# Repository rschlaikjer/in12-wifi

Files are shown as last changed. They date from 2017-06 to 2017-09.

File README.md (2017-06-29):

# Wifi-enabled clock with IN-12 nixies

### Nixie clock that synchronizes over Network Time Protocol

Relatively simple Nixie clock, but with an automatic time detection twist.
On boot, and then every hour after, the clock will synchronize with a network
time server to ensure that it is still correct. No need to manually set the
time, no need to worry about RE-setting the time for daylight savings.
The core components are the MCU (ATMEGA328P), WiFi chipset (ATWINC1500)
and boost converter for the nixie tubes (MAX1771).

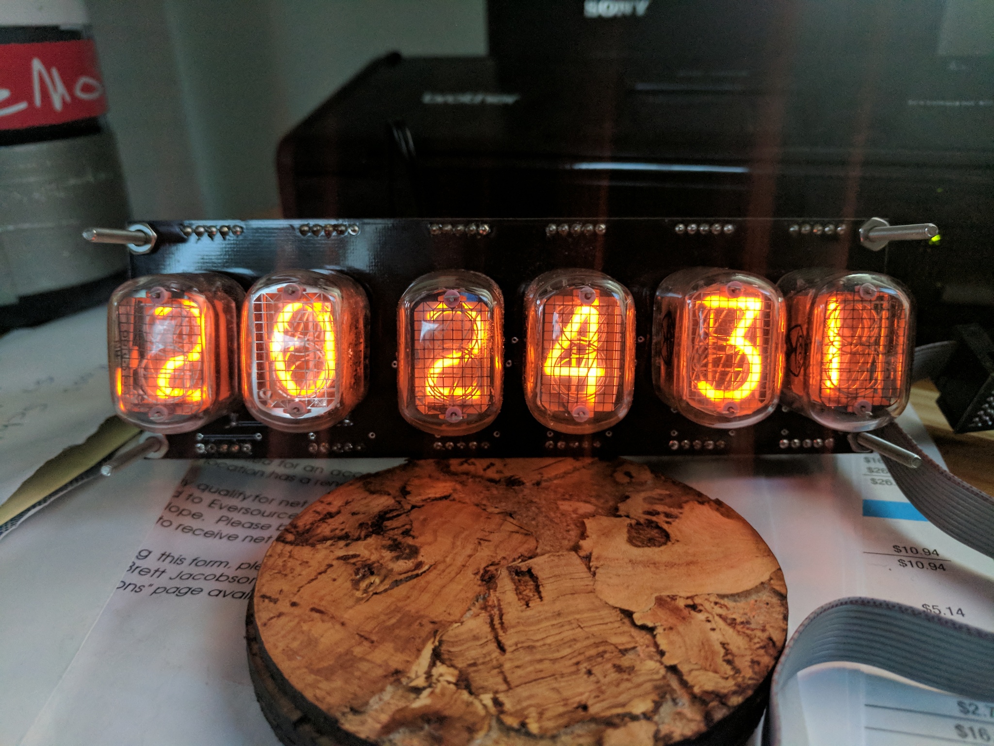
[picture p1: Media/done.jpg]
All set


This project builds on a
[previous clock](https://github.com/rschlaikjer/ntp-nixie)
, which was also NTP-powered but
required a wired internet connection. After the ethernet chipset on that clock
died after a few years continuous service, I resolved to build a second
generation design with two improvements - a seconds place, and wifi enabled to
avoid yet another cable snaking across the desk.

<p align="center">
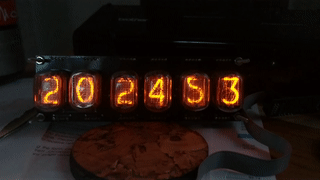
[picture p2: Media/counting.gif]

</p>

The design is split into three PCBs:
- The control board has three sections - one for the boost logic (12V -> 170V),
  one for the wifi logic (at 3.3V), and one for the MCU itsef at 5V.
- The shift register board, middle, simply converts the serial output from the
  MCU on the control board into a parallel output enabling various sinks on the
  nixie pins through MPSA42 transistors.
- The front PCB simply breaks the nixie pins out into even rows at the edges,
  so that it meshes well with the shift register board. Dealing with routing
  the shift registers, current limiting resistors and transistors all on the
  same board as the nixies was too troublesome compared with simply adding
  another layer.

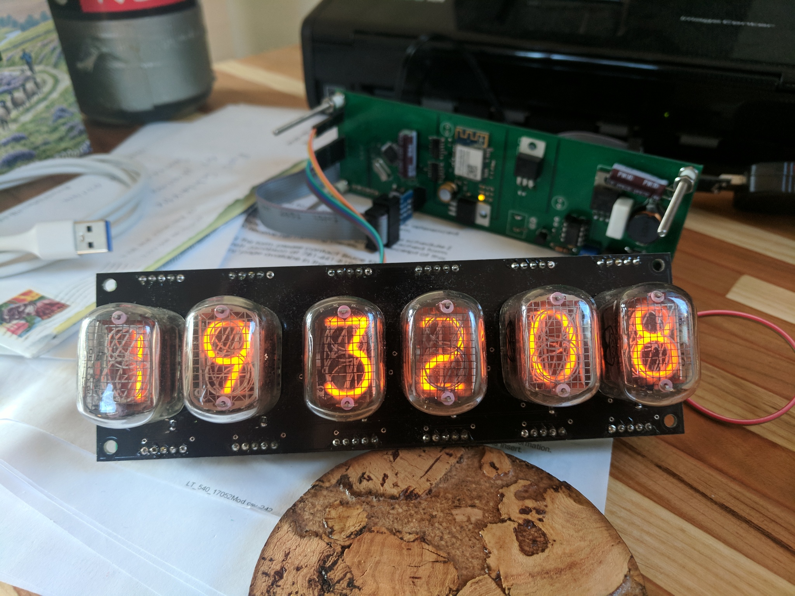
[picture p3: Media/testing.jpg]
Verifying shift register outputs


## BOMs

### Control board

| Part | Value | Device | Package | Description | PROD_ID | VALUE |
| -- | -- | -- | -- | -- | -- | -- |
| C1 | 10uF | CAP0805 | 0805 | Capacitor |  |  |
| C2 | 10uF,25V | CAP_POLPTH2 | CPOL-RADIAL-10UF-25V | Capacitor Polarized |  |  |
| C3 | 10uF/250V | CAP_POLPTH2 | CPOL-RADIAL-10UF-25V | Capacitor Polarized |  |  |
| C4 | 100n | CAPPTH | CAP-PTH-SMALL | Capacitor |  |  |
| C5 | 100n | CAPPTH | CAP-PTH-SMALL | Capacitor |  |  |
| C6 | 100nF | CAP0805 | 0805 | Capacitor |  |  |
| C7 | 10nF | CAP0805 | 0805 | Capacitor |  |  |
| C8 |  | CPOL-USE2,5-6E | E2,5-6E | POLARIZED CAPACITOR, American symbol |  |  |
| C9 |  | CPOL-USE2,5-6E | E2,5-6E | POLARIZED CAPACITOR, American symbol |  |  |
| C10 | 100uF,35V | CAP_POLPTH2 | CPOL-RADIAL-10UF-25V | Capacitor Polarized |  |  |
| C11 | 100nF | CAP0805 | 0805 | Capacitor |  |  |
| C12 | 22pF | CAP0805 | 0805 | Capacitor |  |  |
| C13 | 22pF | CAP0805 | 0805 | Capacitor |  |  |
| C14 | 10uF | CAP0805 | 0805 | Capacitor |  |  |
| C15 |  | CPOL-USE2,5-6E | E2,5-6E | POLARIZED CAPACITOR, American symbol |  |  |
| C16 | 10uF | CAP0805 | 0805 | Capacitor |  |  |
| C17 |  | CPOL-USE2,5-6E | E2,5-6E | POLARIZED CAPACITOR, American symbol |  |  |
| D1 | 1N4007 | 1N4004 | DO41-10 | DIODE |  |  |
| FTDI |  | ARDUINO_SERIAL_PROGRAMPTH | 1X06 | FTDI connector footprints |  |  |
| H1 | STAND-OFF | STAND-OFF | STAND-OFF | #4 Stand Off |  |  |
| H2 | STAND-OFF | STAND-OFF | STAND-OFF | #4 Stand Off |  |  |
| H3 | STAND-OFF | STAND-OFF | STAND-OFF | #4 Stand Off |  |  |
| H4 | STAND-OFF | STAND-OFF | STAND-OFF | #4 Stand Off |  |  |
| IC1 | 7805T | 7805T | TO220H | Positive VOLTAGE REGULATOR |  |  |
| IC3 | ATWINC1500 | ATWINC1500 | ATWINC1500-MR210 | Atmel ATWINC1500-MR210 WiFi/WLAN 802.11 b/g/n |  |  |
| IC4 | LD117AV33 | LD117AV33 | TO220L1 | Low drop fixed and adjustable positive voltage regulators 1 A |  |  |
| ISP1 | AVRISP-6 | AVRISP-6 | AVRISP | AVR ISP HEADER |  |  |
| J1 |  | M04PTH | 1X04 | Header 4 | CONN-09696 |  |
| J2 |  | M02PTH | 1X02 | Standard 2-pin 0.1" header. Use with |  |  |
| J7 |  | M02PTH | 1X02 | Standard 2-pin 0.1" header. Use with |  |  |
| J9 |  | M02PTH | 1X02 | Standard 2-pin 0.1" header. Use with |  |  |
| L1 | 100uH | L-SMT-POWER-B82479 | L-B82479 | SMT power inductors |  |  |
| LED_ACT |  | LED0603 | LED-0603 | LEDs |  |  |
| LED_ERR |  | LED0603 | LED-0603 | LEDs |  |  |
| LED_WIFI |  | LED0603 | LED-0603 | LEDs |  |  |
| Q1 | IRF840 | IRF840 | TO220 | N-Channel Enhancement MOSFET (HEXFET); 500V; 8A; 0,85Ohm |  |  |
| Q2 | MOSFET-NCHANNEL2N7000 | MOSFET-NCHANNEL2N7000 | TO-92 | Common NMOSFET Parts |  |  |
| R1 | 1k | RESISTOR0805-RES | 0805 | Resistor |  |  |
| R2 | 100k | RESISTOR0805-RES | 0805 | Resistor |  |  |
| R3 | 1.5M | RESISTORPTH-1/4W | AXIAL-0.4 | Resistor |  |  |
| R4 | 10k | RESISTORPTH-1/4W | AXIAL-0.4 | Resistor |  |  |
| R5 | 0R050 | RESISTORPTH-1/4W | AXIAL-0.4 | Resistor |  |  |
| R6 | 1lk | RESISTOR0805-RES | 0805 | Resistor |  |  |
| R7 | 1k | RESISTOR0805-RES | 0805 | Resistor |  |  |
| R11 | 100k | RESISTOR0805-RES | 0805 | Resistor |  |  |
| R12 | 100k | RESISTOR0805-RES | 0805 | Resistor |  |  |
| R13 | 100k | RESISTOR0805-RES | 0805 | Resistor |  |  |
| RESET_SW1 | SPST | TACTILE-SWITCH-PTH | TAC-SWITCH-PTH | Tactile Switch 4 Pins, SPST NO |  |  |
| U$3 | MAX1771 | MAX1771 | 8-DIP |  |  |  |
| U$4 | 5k | RTRIM-3362P | RTRIM3362P | BOURNS 3362 - 1/4" Square Trimpot® Trimming Potentiometer |  |  |
| U$19 | PJ-044A | PJ-044A | PJ-044A |  |  |  |
| U1 |  | TXB0104PWRSOIC14 | SO14 | 4-Bit Bi-Directional Level Shifter | IC-11329 |  |
| U2 |  | TXB0104PWRSOIC14 | SO14 | 4-Bit Bi-Directional Level Shifter | IC-11329 |  |
| U3 | ATMEGA328P_TQFP | ATMEGA328P_TQFP | TQFP32-08 |  | IC-09069 | ATMEGA328P_TQFP |
| Y3 | 16MHz | CRYSTALHC49US | HC49US | Various standard crystals. Proven footprints. |  |  |

### Shift register board

| Part | Value | Device | Package | Description | PROD_ID | VALUE |
| -- | -- | -- | -- | -- | -- | -- |
| C1 |  | CAP0805 | 0805 | Capacitor |  |  |
| C2 |  | CAP0805 | 0805 | Capacitor |  |  |
| C3 |  | CAP0805 | 0805 | Capacitor |  |  |
| C4 |  | CAP0805 | 0805 | Capacitor |  |  |
| C5 |  | CAP0805 | 0805 | Capacitor |  |  |
| C6 |  | CAP0805 | 0805 | Capacitor |  |  |
| H1 | STAND-OFF | STAND-OFF | STAND-OFF | #4 Stand Off |  |  |
| H2 | STAND-OFF | STAND-OFF | STAND-OFF | #4 Stand Off |  |  |
| H3 | STAND-OFF | STAND-OFF | STAND-OFF | #4 Stand Off |  |  |
| H4 | STAND-OFF | STAND-OFF | STAND-OFF | #4 Stand Off |  |  |
| IC1 | 74LS595D | 74LS595D | SO16 | 8-bit SHIFT REGISTER, output latch |  |  |
| IC2 | 74LS595D | 74LS595D | SO16 | 8-bit SHIFT REGISTER, output latch |  |  |
| IC3 | 74LS595D | 74LS595D | SO16 | 8-bit SHIFT REGISTER, output latch |  |  |
| IC4 | 74LS595D | 74LS595D | SO16 | 8-bit SHIFT REGISTER, output latch |  |  |
| IC5 | 74LS595D | 74LS595D | SO16 | 8-bit SHIFT REGISTER, output latch |  |  |
| IC9 | 74LS595D | 74LS595D | SO16 | 8-bit SHIFT REGISTER, output latch |  |  |
| J1 |  | M04PTH | 1X04 | Header 4 | CONN-09696 |  |
| J2 |  | M05PTH | 1X05 | Header 5 |  |  |
| J3 |  | M05PTH | 1X05 | Header 5 |  |  |
| J4 |  | M05PTH | 1X05 | Header 5 |  |  |
| J5 |  | M05PTH | 1X05 | Header 5 |  |  |
| J6 |  | M05PTH | 1X05 | Header 5 |  |  |
| J7 |  | M02PTH | 1X02 | Standard 2-pin 0.1" header. Use with |  |  |
| J8 |  | M05PTH | 1X05 | Header 5 |  |  |
| J9 |  | M02PTH | 1X02 | Standard 2-pin 0.1" header. Use with |  |  |
| J10 |  | M05PTH | 1X05 | Header 5 |  |  |
| J11 |  | M05PTH | 1X05 | Header 5 |  |  |
| J12 |  | M05PTH | 1X05 | Header 5 |  |  |
| J13 |  | M05PTH | 1X05 | Header 5 |  |  |
| J14 |  | M05PTH | 1X05 | Header 5 |  |  |
| J15 |  | M05PTH | 1X05 | Header 5 |  |  |
| Q8 | MPSA42 | TRANSISTOR_NPNMPSA42 | SOT23-3 | Generic NPN BJT | TRANS-09116 | MPSA42 |
| Q9 | MPSA42 | TRANSISTOR_NPNMPSA42 | SOT23-3 | Generic NPN BJT | TRANS-09116 | MPSA42 |
| Q10 | MPSA42 | TRANSISTOR_NPNMPSA42 | SOT23-3 | Generic NPN BJT | TRANS-09116 | MPSA42 |
| Q11 | MPSA42 | TRANSISTOR_NPNMPSA42 | SOT23-3 | Generic NPN BJT | TRANS-09116 | MPSA42 |
| Q12 | MPSA42 | TRANSISTOR_NPNMPSA42 | SOT23-3 | Generic NPN BJT | TRANS-09116 | MPSA42 |
| Q13 | MPSA42 | TRANSISTOR_NPNMPSA42 | SOT23-3 | Generic NPN BJT | TRANS-09116 | MPSA42 |
| Q14 | MPSA42 | TRANSISTOR_NPNMPSA42 | SOT23-3 | Generic NPN BJT | TRANS-09116 | MPSA42 |
| Q15 | MPSA42 | TRANSISTOR_NPNMPSA42 | SOT23-3 | Generic NPN BJT | TRANS-09116 | MPSA42 |
| Q16 | MPSA42 | TRANSISTOR_NPNMPSA42 | SOT23-3 | Generic NPN BJT | TRANS-09116 | MPSA42 |
| Q17 | MPSA42 | TRANSISTOR_NPNMPSA42 | SOT23-3 | Generic NPN BJT | TRANS-09116 | MPSA42 |
| Q18 | MPSA42 | TRANSISTOR_NPNMPSA42 | SOT23-3 | Generic NPN BJT | TRANS-09116 | MPSA42 |
| Q19 | MPSA42 | TRANSISTOR_NPNMPSA42 | SOT23-3 | Generic NPN BJT | TRANS-09116 | MPSA42 |
| Q20 | MPSA42 | TRANSISTOR_NPNMPSA42 | SOT23-3 | Generic NPN BJT | TRANS-09116 | MPSA42 |
| Q25 | MPSA42 | TRANSISTOR_NPNMPSA42 | SOT23-3 | Generic NPN BJT | TRANS-09116 | MPSA42 |
| Q26 | MPSA42 | TRANSISTOR_NPNMPSA42 | SOT23-3 | Generic NPN BJT | TRANS-09116 | MPSA42 |
| Q27 | MPSA42 | TRANSISTOR_NPNMPSA42 | SOT23-3 | Generic NPN BJT | TRANS-09116 | MPSA42 |
| Q28 | MPSA42 | TRANSISTOR_NPNMPSA42 | SOT23-3 | Generic NPN BJT | TRANS-09116 | MPSA42 |
| Q29 | MPSA42 | TRANSISTOR_NPNMPSA42 | SOT23-3 | Generic NPN BJT | TRANS-09116 | MPSA42 |
| Q30 | MPSA42 | TRANSISTOR_NPNMPSA42 | SOT23-3 | Generic NPN BJT | TRANS-09116 | MPSA42 |
| Q31 | MPSA42 | TRANSISTOR_NPNMPSA42 | SOT23-3 | Generic NPN BJT | TRANS-09116 | MPSA42 |
| Q32 | MPSA42 | TRANSISTOR_NPNMPSA42 | SOT23-3 | Generic NPN BJT | TRANS-09116 | MPSA42 |
| Q33 | MPSA42 | TRANSISTOR_NPNMPSA42 | SOT23-3 | Generic NPN BJT | TRANS-09116 | MPSA42 |
| Q34 | MPSA42 | TRANSISTOR_NPNMPSA42 | SOT23-3 | Generic NPN BJT | TRANS-09116 | MPSA42 |
| Q35 | MPSA42 | TRANSISTOR_NPNMPSA42 | SOT23-3 | Generic NPN BJT | TRANS-09116 | MPSA42 |
| Q36 | MPSA42 | TRANSISTOR_NPNMPSA42 | SOT23-3 | Generic NPN BJT | TRANS-09116 | MPSA42 |
| Q37 | MPSA42 | TRANSISTOR_NPNMPSA42 | SOT23-3 | Generic NPN BJT | TRANS-09116 | MPSA42 |
| Q38 | MPSA42 | TRANSISTOR_NPNMPSA42 | SOT23-3 | Generic NPN BJT | TRANS-09116 | MPSA42 |
| Q39 | MPSA42 | TRANSISTOR_NPNMPSA42 | SOT23-3 | Generic NPN BJT | TRANS-09116 | MPSA42 |
| Q40 | MPSA42 | TRANSISTOR_NPNMPSA42 | SOT23-3 | Generic NPN BJT | TRANS-09116 | MPSA42 |
| Q45 | MPSA42 | TRANSISTOR_NPNMPSA42 | SOT23-3 | Generic NPN BJT | TRANS-09116 | MPSA42 |
| Q46 | MPSA42 | TRANSISTOR_NPNMPSA42 | SOT23-3 | Generic NPN BJT | TRANS-09116 | MPSA42 |
| Q47 | MPSA42 | TRANSISTOR_NPNMPSA42 | SOT23-3 | Generic NPN BJT | TRANS-09116 | MPSA42 |
| Q48 | MPSA42 | TRANSISTOR_NPNMPSA42 | SOT23-3 | Generic NPN BJT | TRANS-09116 | MPSA42 |
| Q49 | MPSA42 | TRANSISTOR_NPNMPSA42 | SOT23-3 | Generic NPN BJT | TRANS-09116 | MPSA42 |
| Q50 | MPSA42 | TRANSISTOR_NPNMPSA42 | SOT23-3 | Generic NPN BJT | TRANS-09116 | MPSA42 |
| Q51 | MPSA42 | TRANSISTOR_NPNMPSA42 | SOT23-3 | Generic NPN BJT | TRANS-09116 | MPSA42 |
| Q52 | MPSA42 | TRANSISTOR_NPNMPSA42 | SOT23-3 | Generic NPN BJT | TRANS-09116 | MPSA42 |
| Q53 | MPSA42 | TRANSISTOR_NPNMPSA42 | SOT23-3 | Generic NPN BJT | TRANS-09116 | MPSA42 |
| Q54 | MPSA42 | TRANSISTOR_NPNMPSA42 | SOT23-3 | Generic NPN BJT | TRANS-09116 | MPSA42 |
| Q55 | MPSA42 | TRANSISTOR_NPNMPSA42 | SOT23-3 | Generic NPN BJT | TRANS-09116 | MPSA42 |
| Q56 | MPSA42 | TRANSISTOR_NPNMPSA42 | SOT23-3 | Generic NPN BJT | TRANS-09116 | MPSA42 |
| Q57 | MPSA42 | TRANSISTOR_NPNMPSA42 | SOT23-3 | Generic NPN BJT | TRANS-09116 | MPSA42 |
| Q58 | MPSA42 | TRANSISTOR_NPNMPSA42 | SOT23-3 | Generic NPN BJT | TRANS-09116 | MPSA42 |
| Q59 | MPSA42 | TRANSISTOR_NPNMPSA42 | SOT23-3 | Generic NPN BJT | TRANS-09116 | MPSA42 |
| Q60 | MPSA42 | TRANSISTOR_NPNMPSA42 | SOT23-3 | Generic NPN BJT | TRANS-09116 | MPSA42 |
| R3 |  | RESISTOR0805-RES | 0805 | Resistor |  |  |
| R4 |  | RESISTOR0805-RES | 0805 | Resistor |  |  |
| R5 |  | RESISTOR0805-RES | 0805 | Resistor |  |  |
| R6 |  | RESISTOR0805-RES | 0805 | Resistor |  |  |
| R7 |  | RESISTOR0805-RES | 0805 | Resistor |  |  |
| R8 |  | RESISTOR0805-RES | 0805 | Resistor |  |  |
| R9 |  | RESISTOR0805-RES | 0805 | Resistor |  |  |
| R10 |  | RESISTOR0805-RES | 0805 | Resistor |  |  |
| R11 |  | RESISTOR0805-RES | 0805 | Resistor |  |  |
| R12 |  | RESISTOR0805-RES | 0805 | Resistor |  |  |
| U$1 | CTS744 | CTS744 | CT740-746 |  |  |  |
| U$10 | CTS744 | CTS744 | CT740-746 |  |  |  |
| U$11 | CTS744 | CTS744 | CT740-746 |  |  |  |
| U$12 | CTS744 | CTS744 | CT740-746 |  |  |  |
| U$14 | CTS744 | CTS744 | CT740-746 |  |  |  |
| U$15 | CTS744 | CTS744 | CT740-746 |  |  |  |
| U$16 | CTS744 | CTS744 | CT740-746 |  |  |  |
| U$18 | CTS744 | CTS744 | CT740-746 |  |  |  |
| U$19 | CTS744 | CTS744 | CT740-746 |  |  |  |

### Display board

| Part | Value | Device | Package | Description |  |
| -- | -- | -- | -- | -- | -- |
| H1 | STAND-OFF | STAND-OFF | STAND-OFF | #4 Stand Off |  |
| H2 | STAND-OFF | STAND-OFF | STAND-OFF | #4 Stand Off |  |
| H3 | STAND-OFF | STAND-OFF | STAND-OFF | #4 Stand Off |  |
| H4 | STAND-OFF | STAND-OFF | STAND-OFF | #4 Stand Off |  |
| J1 |  | M02PTH | 1X02 | Standard 2-pin 0.1" header. Use with |  |
| J2 |  | M05PTH | 1X05 | Header 5 |  |
| J3 |  | M05PTH | 1X05 | Header 5 |  |
| J4 |  | M05PTH | 1X05 | Header 5 |  |
| J5 |  | M05PTH | 1X05 | Header 5 |  |
| J6 |  | M05PTH | 1X05 | Header 5 |  |
| J7 |  | M05PTH | 1X05 | Header 5 |  |
| J8 |  | M05PTH | 1X05 | Header 5 |  |
| J9 |  | M05PTH | 1X05 | Header 5 |  |
| J10 |  | M05PTH | 1X05 | Header 5 |  |
| J11 |  | M05PTH | 1X05 | Header 5 |  |
| J12 |  | M05PTH | 1X05 | Header 5 |  |
| J13 |  | M05PTH | 1X05 | Header 5 |  |
| N1 | IN-12A | IN-12A | IN-12 | IN-12A: medium numeric topview nixie tube |  |
| N2 | IN-12A | IN-12A | IN-12 | IN-12A: medium numeric topview nixie tube |  |
| N3 | IN-12A | IN-12A | IN-12 | IN-12A: medium numeric topview nixie tube |  |
| N4 | IN-12A | IN-12A | IN-12 | IN-12A: medium numeric topview nixie tube |  |
| N5 | IN-12A | IN-12A | IN-12 | IN-12A: medium numeric topview nixie tube |  |
| N6 | IN-12A | IN-12A | IN-12 | IN-12A: medium numeric topview nixie tube |  |
| R1 |  | RESISTOR0805-RES | 0805 | Resistor |  |
| R2 |  | RESISTOR0805-RES | 0805 | Resistor |  |
| R3 |  | RESISTOR0805-RES | 0805 | Resistor |  |
| R4 |  | RESISTOR0805-RES | 0805 | Resistor |  |
| R5 |  | RESISTOR0805-RES | 0805 | Resistor |  |
| R6 |  | RESISTOR0805-RES | 0805 | Resistor |  |

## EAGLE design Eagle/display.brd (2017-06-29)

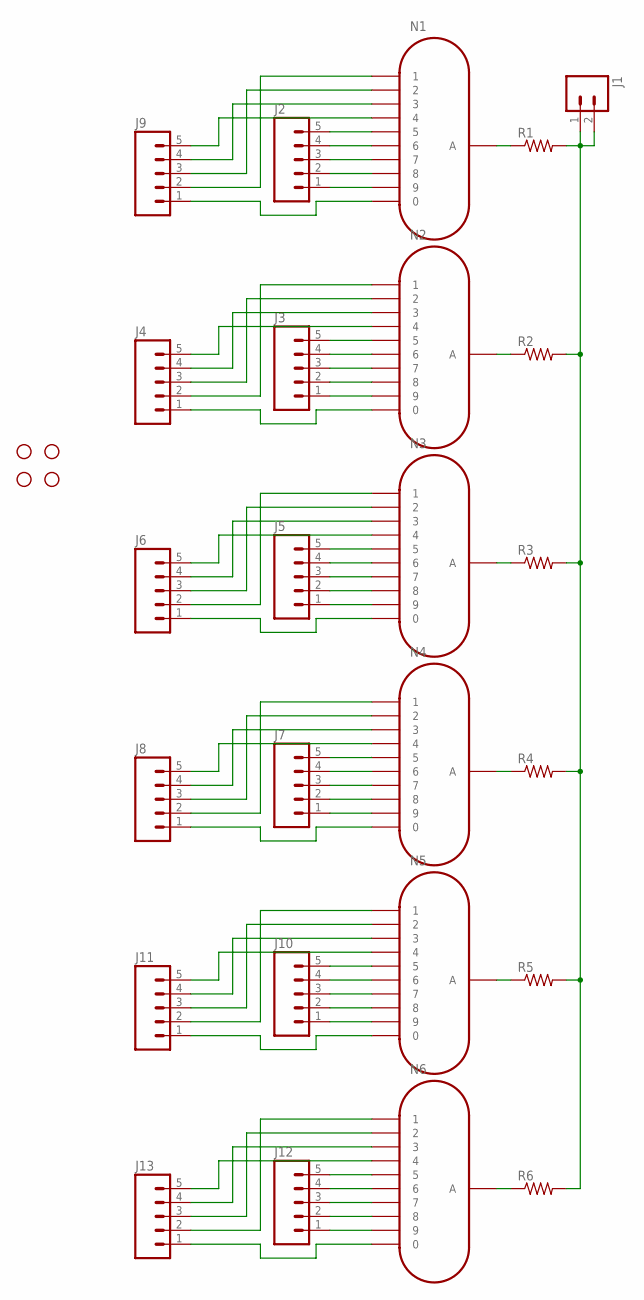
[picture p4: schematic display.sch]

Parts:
H1, H2, H3, H4: STAND-OFF
J1: M02PTH; 1X02
J2, J3, J4, J5, J6, J7, J8, J9, J10, J11, J12, J13: M05PTH; 1X05
N1, N2, N3, N4, N5, N6: IN-12A; IN-12
R1, R2, R3, R4, R5, R6: RESISTOR0805-RES; 0805

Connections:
unnamed: J4.1, N2.0
unnamed: J3.1, N2.9
unnamed: J3.2, N2.8
unnamed: J3.3, N2.7
unnamed: J3.4, N2.6
unnamed: J4.3, N2.2
unnamed: J4.4, N2.3
unnamed: J4.5, N2.4
unnamed: J3.5, N2.5
unnamed: J4.2, N2.1
unnamed: J2.1, N1.9
unnamed: J2.2, N1.8
unnamed: J2.3, N1.7
unnamed: J2.4, N1.6
unnamed: J2.5, N1.5
unnamed: J9.2, N1.1
unnamed: J9.3, N1.2
unnamed: J9.4, N1.3
unnamed: J9.5, N1.4
unnamed: J9.1, N1.0
unnamed: J6.1, N3.0
unnamed: J5.1, N3.9
unnamed: J5.2, N3.8
unnamed: J5.3, N3.7
unnamed: J5.4, N3.6
unnamed: J5.5, N3.5
unnamed: J6.2, N3.1
unnamed: J6.3, N3.2
unnamed: J6.4, N3.3
unnamed: J6.5, N3.4
unnamed: J8.1, N4.0
unnamed: J7.1, N4.9
unnamed: J7.2, N4.8
unnamed: J7.3, N4.7
unnamed: J7.4, N4.6
unnamed: J7.5, N4.5
unnamed: J8.2, N4.1
unnamed: J8.3, N4.2
unnamed: J8.4, N4.3
unnamed: J8.5, N4.4
unnamed: J11.1, N5.0
unnamed: J10.1, N5.9
unnamed: J10.2, N5.8
unnamed: J10.3, N5.7
unnamed: J10.4, N5.6
unnamed: J10.5, N5.5
unnamed: J11.2, N5.1
unnamed: J11.3, N5.2
unnamed: J11.4, N5.3
unnamed: J11.5, N5.4
unnamed: J13.1, N6.0
unnamed: J12.1, N6.9
unnamed: J12.2, N6.8
unnamed: J12.3, N6.7
unnamed: J12.4, N6.6
unnamed: J12.5, N6.5
unnamed: J13.2, N6.1
unnamed: J13.3, N6.2
unnamed: J13.4, N6.3
unnamed: J13.5, N6.4
unnamed: N1.A, R1.1
unnamed: N2.A, R2.1
unnamed: N3.A, R3.1
unnamed: N4.A, R4.1
unnamed: N5.A, R5.1
unnamed: N6.A, R6.1
unnamed: J1.1, J1.2, R1.2, R2.2, R3.2, R4.2, R5.2, R6.2

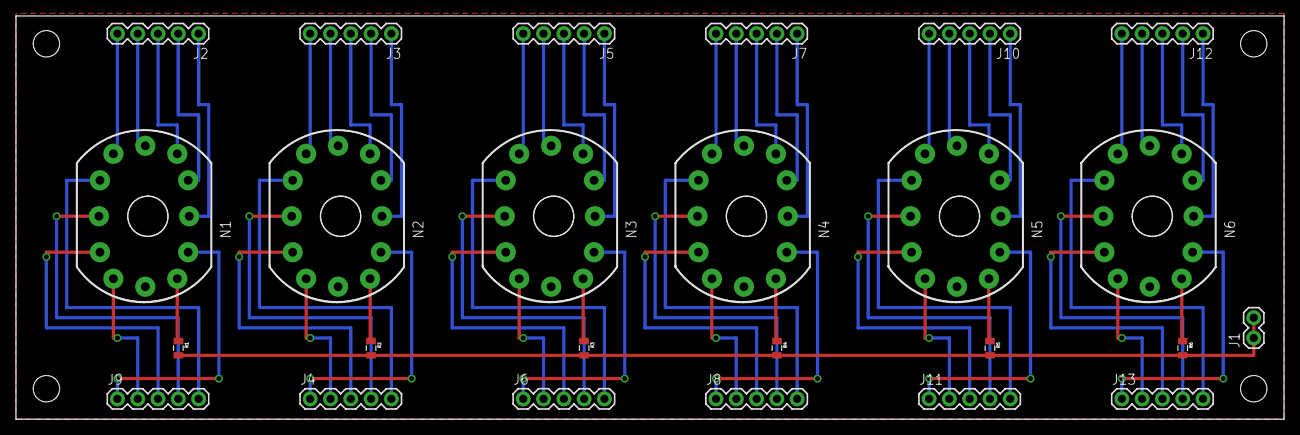
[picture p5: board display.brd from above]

Board: 2 copper layers, 158.7 x 50.5 mm, 29 parts (0 on the bottom side), 67 nets.

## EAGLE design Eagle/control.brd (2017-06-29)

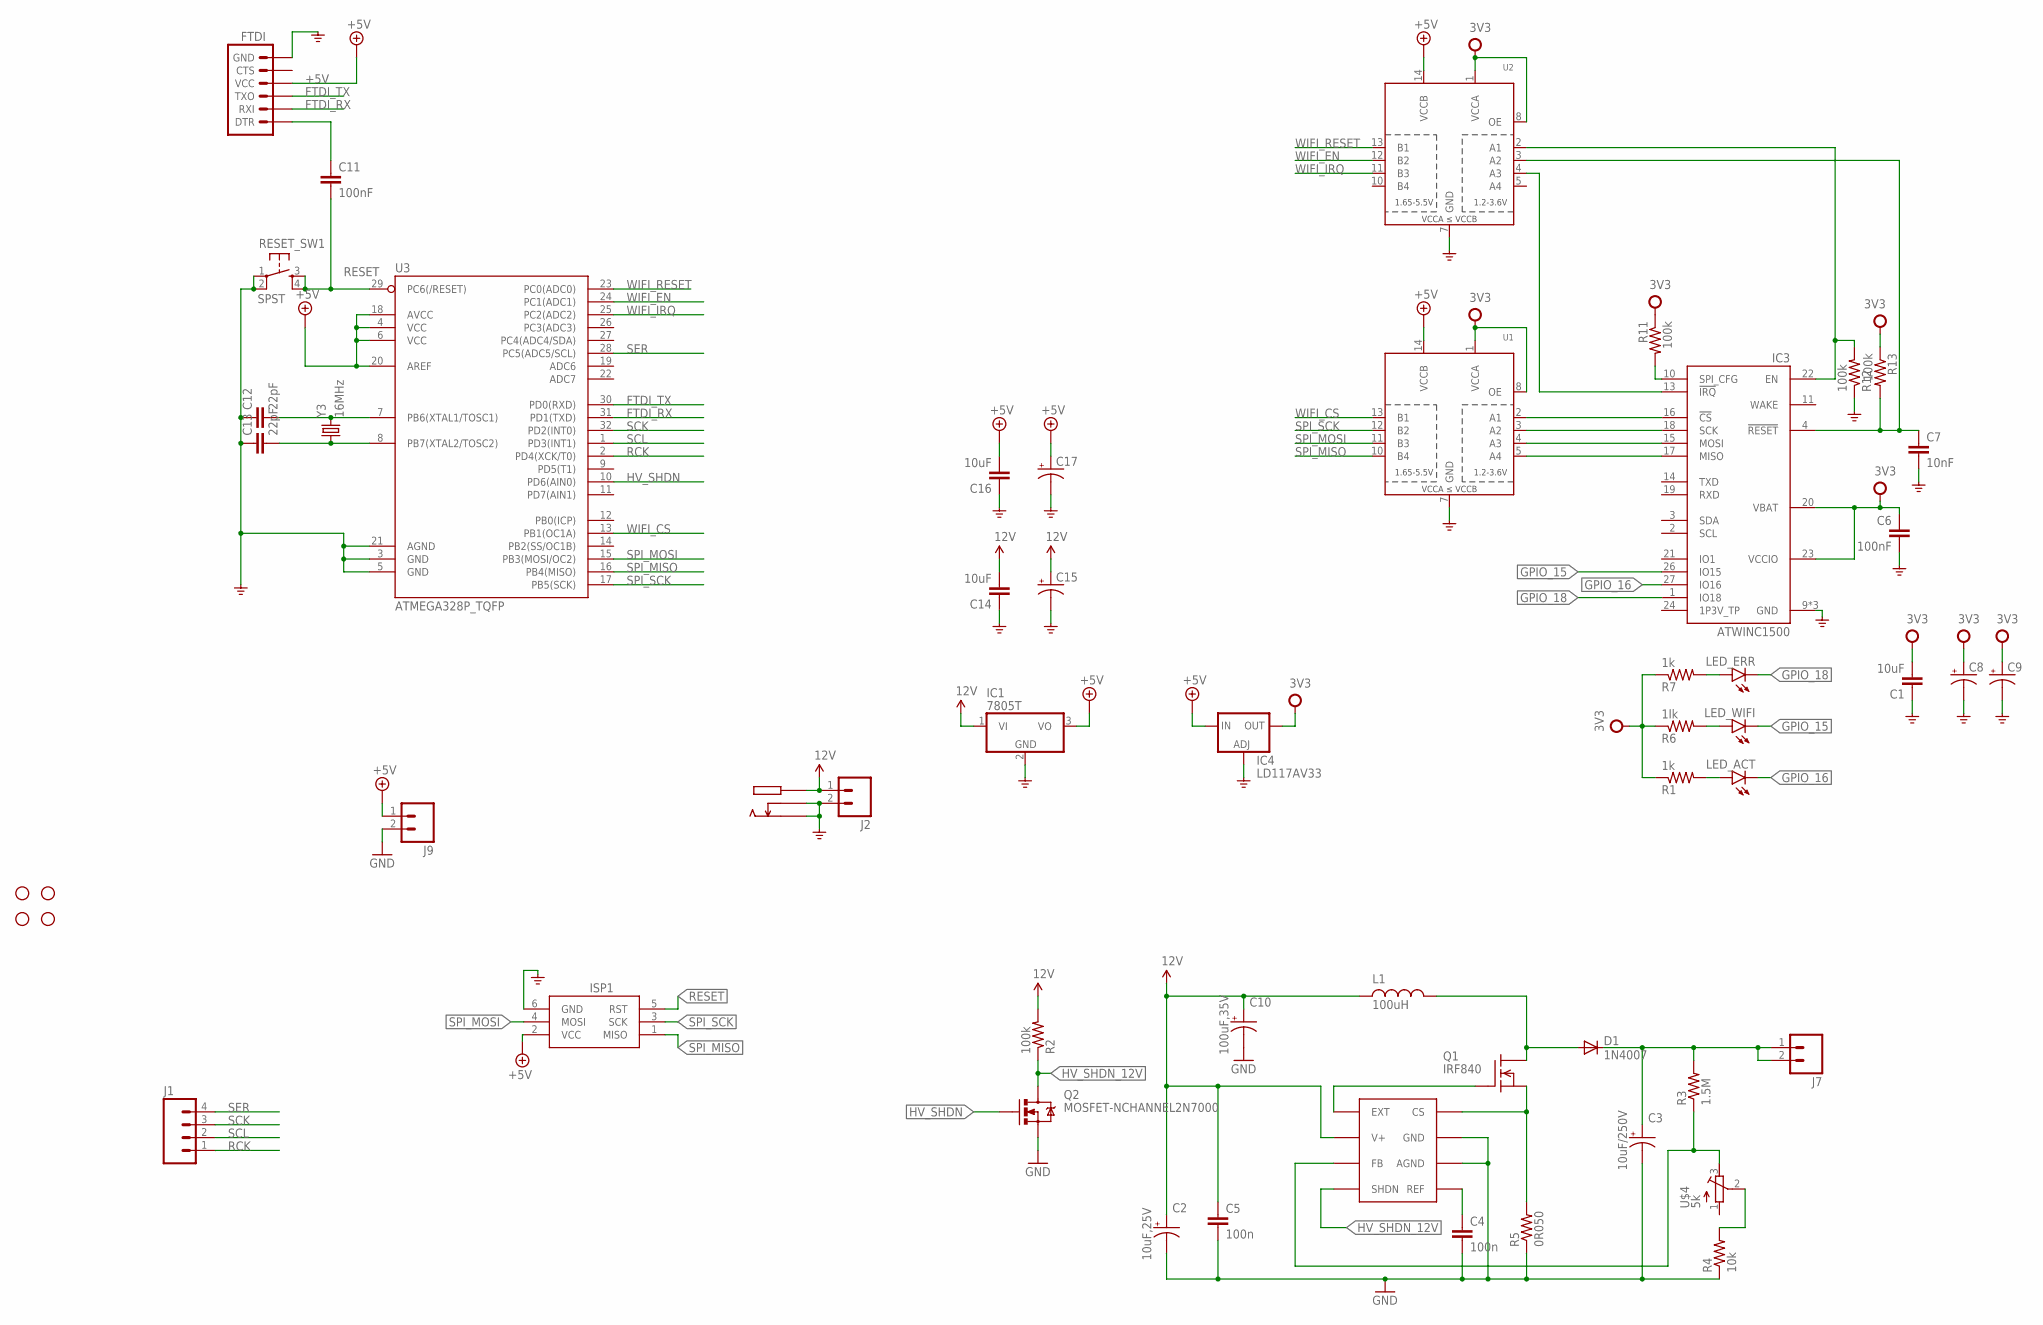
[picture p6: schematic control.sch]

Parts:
C1, C14, C16: 10uF; 0805
C2: 10uF,25V; CPOL-RADIAL-10UF-25V
C3: 10uF/250V; CPOL-RADIAL-10UF-25V
C4, C5: 100n; CAP-PTH-SMALL
C6, C11: 100nF; 0805
C7: 10nF; 0805
C8, C9, C15, C17: CPOL-USE2,5-6E; E2,5-6E
C10: 100uF,35V; CPOL-RADIAL-10UF-25V
C12, C13: 22pF; 0805
D1: 1N4007; DO41-10
FTDI: ARDUINO_SERIAL_PROGRAMPTH; 1X06
H1, H2, H3, H4: STAND-OFF
IC1: 7805T; TO220H
IC3: ATWINC1500; ATWINC1500-MR210
IC4: LD117AV33; TO220L1
ISP1: AVRISP-6; AVRISP
J1: M04PTH; 1X04
J2, J7, J9: M02PTH; 1X02
L1: 100uH; L-B82479
LED_ACT: LED0603; LED-0603
LED_ERR: LED0603; LED-0603
LED_WIFI: LED0603; LED-0603
Q1: IRF840; TO220
Q2: MOSFET-NCHANNEL2N7000; TO-92
R1, R7: 1k; 0805
R2, R11, R12, R13: 100k; 0805
R3: 1.5M; AXIAL-0.4
R4: 10k; AXIAL-0.4
R5: 0R050; AXIAL-0.4
R6: 1lk; 0805
RESET_SW1: SPST; TAC-SWITCH-PTH
U1, U2: TXB0104PWRSOIC14; SO14
U3: ATMEGA328P_TQFP; TQFP32-08
U$3: MAX1771; 8-DIP
U$4: 5k; RTRIM3362P
U$19: PJ-044A
Y3: 16MHz; HC49US

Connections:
12V: C2.1 (+), C5.1, C10.1 (+), C14.2, C15.+, IC1.1 (VI), J2.1, L1.P$1 (1), R2.2, U$3.V+, U$19.1, U$19.P1 (1)
+3V3: C1.2, C6.1, C8.+, C9.+, IC3.20 (VBAT), IC3.23 (VCCIO), IC4.2 (OUT), R1.1, R6.1, R7.1, R11.1, R13.1, U1.1 (VCCA), U1.8 (OE), U2.1 (VCCA), U2.8 (OE)
+5V: C16.2, C17.+, FTDI.4 (VCC), IC1.3 (VO), IC4.3 (IN), ISP1.2 (VCC), J9.1, U1.14 (VCCB), U2.14 (VCCB), U3.4 (VCC), U3.6 (VCC), U3.18 (AVCC), U3.20 (AREF)
EXT1: Q1.1 (G), U$3.EXT
FTDI_RX: FTDI.2 (RXI), U3.31 (PD1(TXD))
FTDI_TX: FTDI.3 (TXO), U3.30 (PD0(RXD))
GND: C1.1, C2.2 (-), C3.2 (-), C4.2, C5.2, C6.2, C7.2, C8.-, C9.-, C10.2 (-), C12.1, C13.1, C14.1, C15.-, C16.1, C17.-, FTDI.6 (GND), IC1.2 (GND), IC3.9 (GND), IC3.12 (GND), IC3.28 (GND), IC4.1 (ADJ), ISP1.6 (GND), J2.2, J9.2, Q2.1 (S), R4.P$1 (1), R5.P$1 (1), R12.1, RESET_SW1.1, RESET_SW1.2, U1.7 (GND), U2.7 (GND), U3.3 (GND), U3.5 (GND), U3.21 (AGND), U$3.AGND, U$3.GND, U$19.2, U$19.3, U$19.P2 (2), U$19.P3 (3)
GPIO_15: IC3.26 (IO15), LED_WIFI.C
GPIO_16: IC3.27 (IO16), LED_ACT.C
GPIO_18: IC3.1 (IO18), LED_ERR.C
HV_GEIGER: C3.1 (+), D1.C, J7.1, J7.2, R3.P$2 (2)
HV_SHDN: Q2.2 (G), U3.10 (PD6(AIN0))
HV_SHDN_12V: Q2.3 (D), R2.1, U$3.SHDN
unnamed: R3.P$1 (1), U$3.FB, U$4.3
unnamed: D1.A, L1.P$2 (2), Q1.2 (D)
unnamed: Q1.3 (S), R5.P$2 (2), U$3.CS
unnamed: C4.1, U$3.REF
unnamed: R4.P$2 (2), U$4.2
unnamed: LED_ACT.A, R1.2
unnamed: IC3.10 (SPI_CFG), R11.2
unnamed: LED_WIFI.A, R6.2
unnamed: LED_ERR.A, R7.2
unnamed: IC3.16 (!CS), U1.2 (A1)
unnamed: IC3.18 (SCK), U1.3 (A2)
unnamed: IC3.15 (MOSI), U1.4 (A3)
unnamed: IC3.17 (MISO), U1.5 (A4)
unnamed: IC3.13 (!IRQ), U2.4 (A3)
unnamed: IC3.22 (EN), R12.2, U2.2 (A1)
unnamed: C12.2, U3.7 (PB6(XTAL1/TOSC1)), Y3.2
unnamed: C13.2, U3.8 (PB7(XTAL2/TOSC2)), Y3.1
unnamed: C7.1, IC3.4 (!RESET), R13.2, U2.3 (A2)
unnamed: C11.1, FTDI.1 (DTR)
RCK: J1.1, U3.2 (PD4(XCK/T0))
RESET: C11.2, ISP1.5 (RST), RESET_SW1.3, RESET_SW1.4, U3.29 (PC6(/RESET))
SCK: J1.3, U3.32 (PD2(INT0))
SCL: J1.2, U3.1 (PD3(INT1))
SER: J1.4, U3.28 (PC5(ADC5/SCL))
SPI_MISO: ISP1.1 (MISO), U1.10 (B4), U3.16 (PB4(MISO))
SPI_MOSI: ISP1.4 (MOSI), U1.11 (B3), U3.15 (PB3(MOSI/OC2))
SPI_SCK: ISP1.3 (SCK), U1.12 (B2), U3.17 (PB5(SCK))
WIFI_CS: U1.13 (B1), U3.13 (PB1(OC1A))
WIFI_EN: U2.12 (B2), U3.24 (PC1(ADC1))
WIFI_IRQ: U2.11 (B3), U3.25 (PC2(ADC2))
WIFI_RESET: U2.13 (B1), U3.23 (PC0(ADC0))

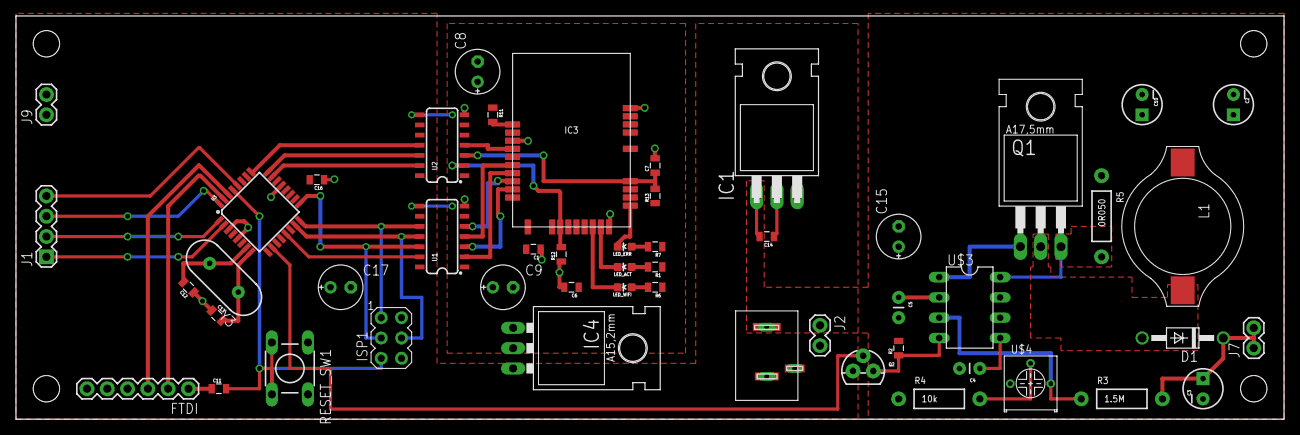
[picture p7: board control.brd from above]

Board: 2 copper layers, 158.7 x 50.5 mm, 55 parts (0 on the bottom side), 44 nets.

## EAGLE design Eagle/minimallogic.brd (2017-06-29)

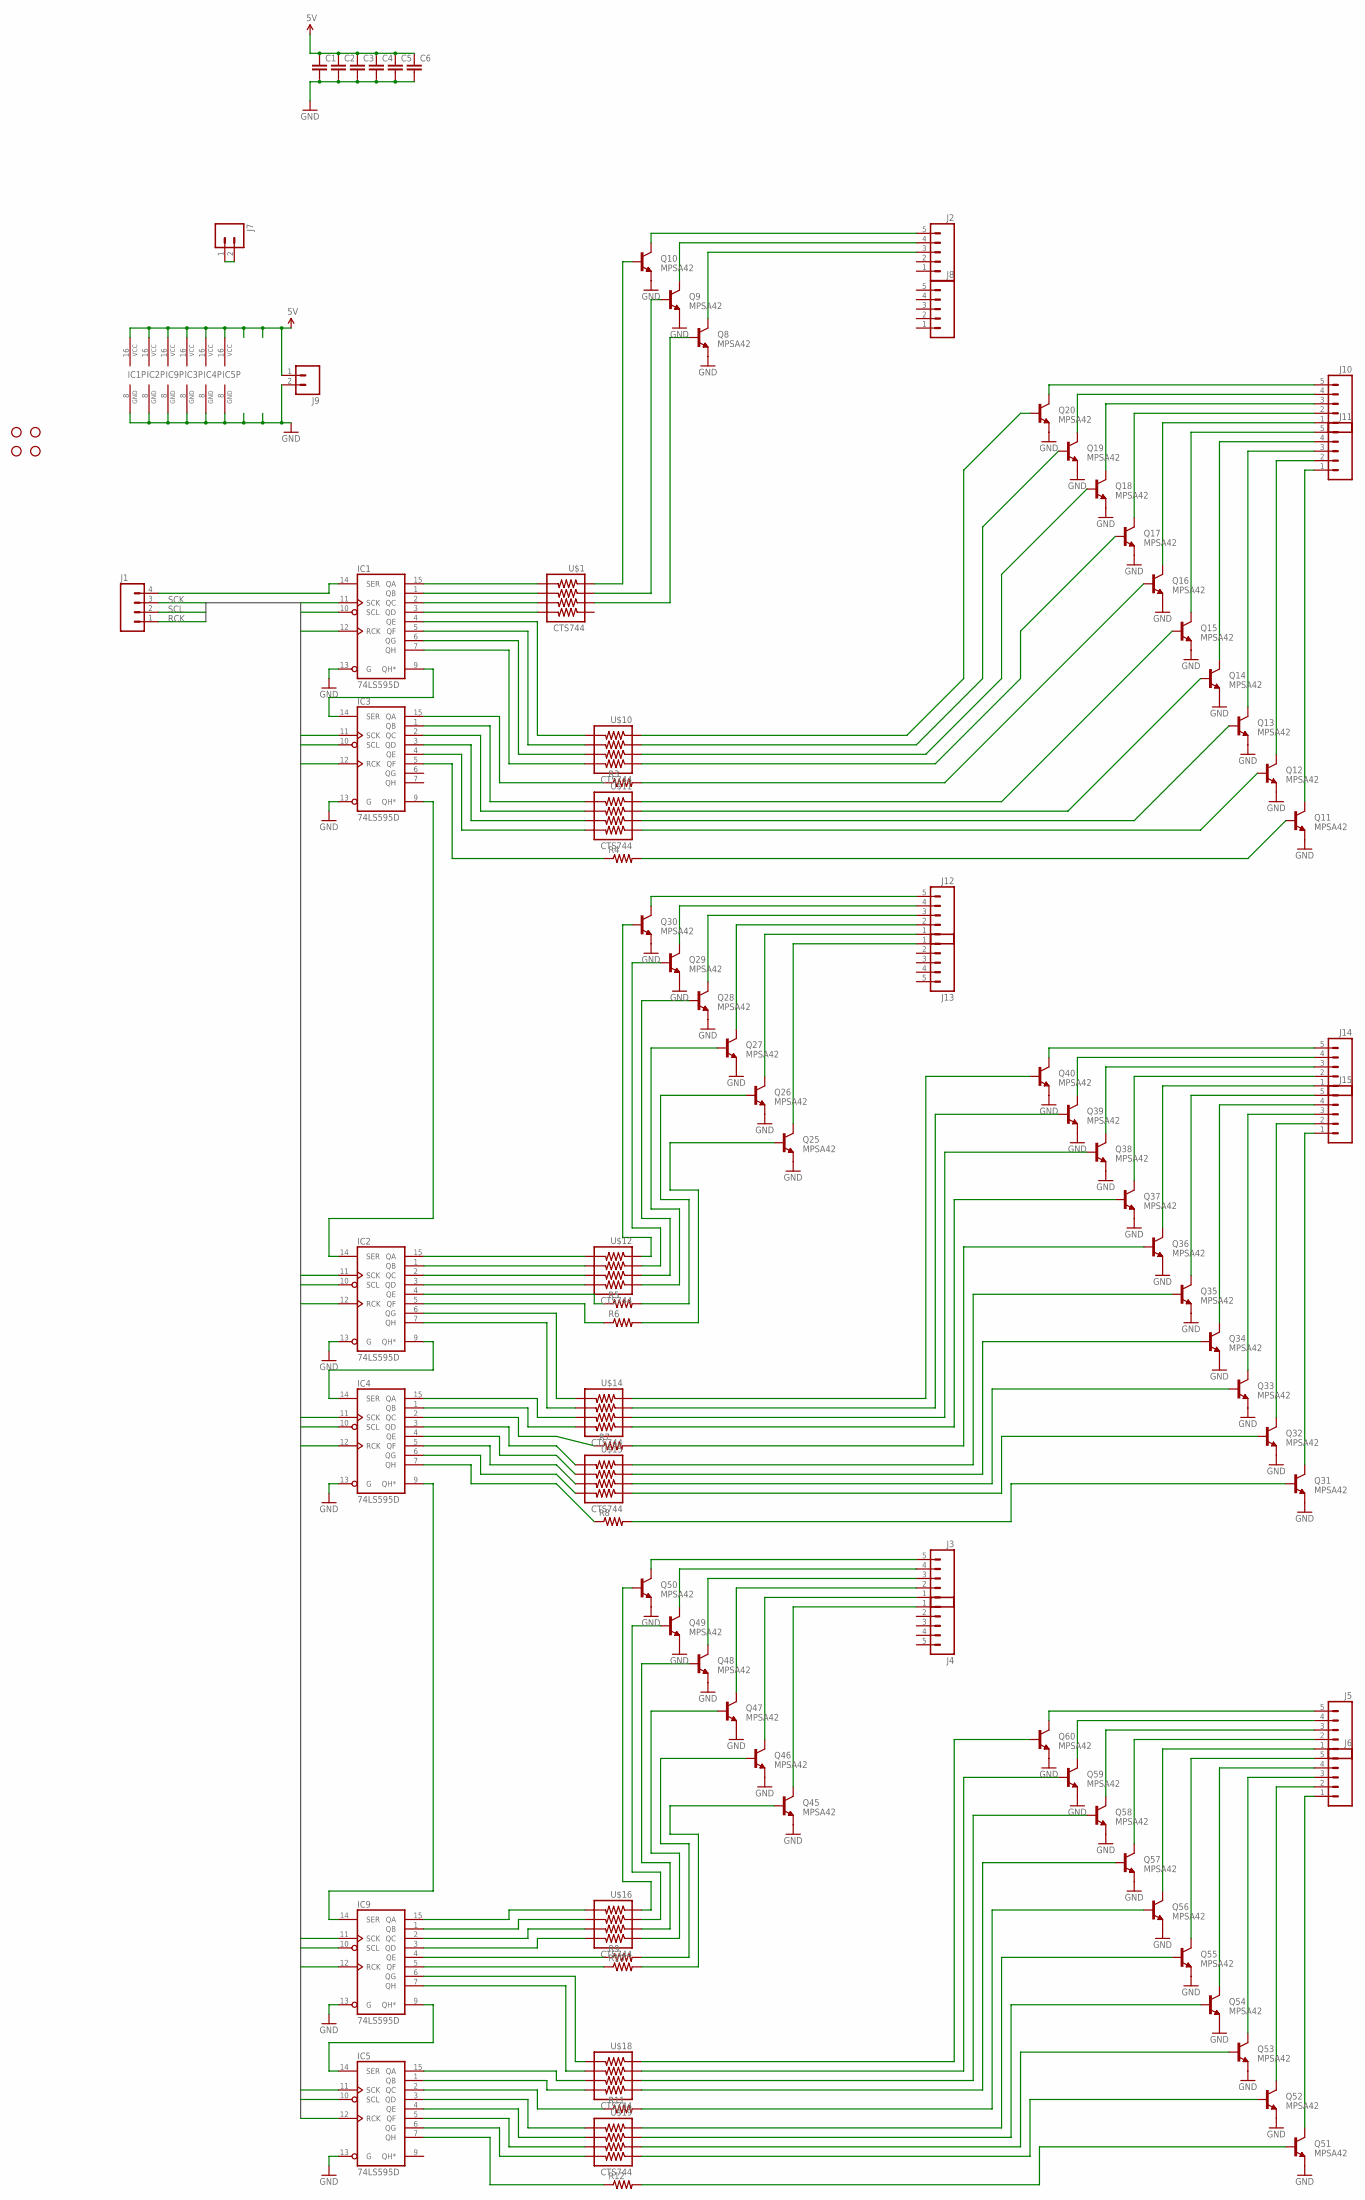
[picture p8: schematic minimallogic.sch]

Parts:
C1, C2, C3, C4, C5, C6: CAP0805; 0805
H1, H2, H3, H4: STAND-OFF
IC1, IC2, IC3, IC4, IC5, IC9: 74LS595D; SO16
J1: M04PTH; 1X04
J2, J3, J4, J5, J6, J8, J10, J11, J12, J13, J14, J15: M05PTH; 1X05
J7, J9: M02PTH; 1X02
Q8, Q9, Q10, Q11, Q12, Q13, Q14, Q15, Q16, Q17, Q18, Q19, Q20, Q25, Q26, Q27, Q28, Q29, Q30, Q31, Q32, Q33, Q34, Q35, Q36, Q37, Q38, Q39, Q40, Q45, Q46, Q47, Q48, Q49, Q50, Q51, Q52, Q53, Q54, Q55, Q56, Q57, Q58, Q59, Q60: MPSA42; SOT23-3
R3, R4, R5, R6, R7, R8, R9, R10, R11, R12: RESISTOR0805-RES; 0805
U$1, U$10, U$11, U$12, U$14, U$15, U$16, U$18, U$19: CTS744; CT740-746

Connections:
5V: C1.1, C2.1, C3.1, C4.1, C5.1, C6.1, IC1.16 (VCC), IC2.16 (VCC), IC3.16 (VCC), IC4.16 (VCC), IC5.16 (VCC), IC9.16 (VCC), J9.1
GND: C1.2, C2.2, C3.2, C4.2, C5.2, C6.2, IC1.8 (GND), IC1.13 (G), IC2.8 (GND), IC2.13 (G), IC3.8 (GND), IC3.13 (G), IC4.8 (GND), IC4.13 (G), IC5.8 (GND), IC5.13 (G), IC9.8 (GND), IC9.13 (G), J9.2, Q8.2 (E), Q9.2 (E), Q10.2 (E), Q11.2 (E), Q12.2 (E), Q13.2 (E), Q14.2 (E), Q15.2 (E), Q16.2 (E), Q17.2 (E), Q18.2 (E), Q19.2 (E), Q20.2 (E), Q25.2 (E), Q26.2 (E), Q27.2 (E), Q28.2 (E), Q29.2 (E), Q30.2 (E), Q31.2 (E), Q32.2 (E), Q33.2 (E), Q34.2 (E), Q35.2 (E), Q36.2 (E), Q37.2 (E), Q38.2 (E), Q39.2 (E), Q40.2 (E), Q45.2 (E), Q46.2 (E), Q47.2 (E), Q48.2 (E), Q49.2 (E), Q50.2 (E), Q51.2 (E), Q52.2 (E), Q53.2 (E), Q54.2 (E), Q55.2 (E), Q56.2 (E), Q57.2 (E), Q58.2 (E), Q59.2 (E), Q60.2 (E)
unnamed: IC1.4 (QE), U$10.P8 (OUT1)
unnamed: IC1.5 (QF), U$10.P7 (OUT2)
unnamed: IC1.6 (QG), U$10.P6 (OUT3)
unnamed: IC1.7 (QH), U$10.P5 (OUT4)
unnamed: IC2.5 (QF), R6.1
unnamed: IC2.4 (QE), R5.1
unnamed: IC2.9 (QH*), IC4.14 (SER)
unnamed: IC9.15 (QA), U$16.P8 (OUT1)
unnamed: J13.1, Q25.3 (C)
unnamed: J12.1, Q26.3 (C)
unnamed: J11.1, Q11.3 (C)
unnamed: J11.2, Q12.3 (C)
unnamed: J11.3, Q13.3 (C)
unnamed: J11.4, Q14.3 (C)
unnamed: J11.5, Q15.3 (C)
unnamed: J10.1, Q16.3 (C)
unnamed: J10.2, Q17.3 (C)
unnamed: J10.3, Q18.3 (C)
unnamed: J10.4, Q19.3 (C)
unnamed: J10.5, Q20.3 (C)
unnamed: IC1.9 (QH*), IC3.14 (SER)
unnamed: IC1.15 (QA), U$1.P8 (OUT1)
unnamed: IC1.1 (QB), U$1.P7 (OUT2)
unnamed: IC1.2 (QC), U$1.P6 (OUT3)
unnamed: IC1.3 (QD), U$1.P5 (OUT4)
unnamed: IC3.15 (QA), R3.1
unnamed: IC3.1 (QB), U$11.P8 (OUT1)
unnamed: IC3.2 (QC), U$11.P7 (OUT2)
unnamed: IC3.3 (QD), U$11.P6 (OUT3)
unnamed: IC3.4 (QE), U$11.P5 (OUT4)
unnamed: IC3.5 (QF), R4.1
unnamed: IC9.1 (QB), U$16.P7 (OUT2)
unnamed: IC9.2 (QC), U$16.P6 (OUT3)
unnamed: IC9.3 (QD), U$16.P5 (OUT4)
unnamed: IC9.4 (QE), R9.1
unnamed: IC9.5 (QF), R10.1
unnamed: IC2.15 (QA), U$12.P8 (OUT1)
unnamed: IC2.1 (QB), U$12.P7 (OUT2)
unnamed: IC2.2 (QC), U$12.P6 (OUT3)
unnamed: IC2.3 (QD), U$12.P5 (OUT4)
unnamed: IC5.14 (SER), IC9.9 (QH*)
unnamed: J12.2, Q27.3 (C)
unnamed: IC4.9 (QH*), IC9.14 (SER)
unnamed: IC9.6 (QG), U$18.P8 (OUT1)
unnamed: IC9.7 (QH), U$18.P7 (OUT2)
unnamed: IC5.15 (QA), U$18.P6 (OUT3)
unnamed: IC2.6 (QG), U$14.P8 (OUT1)
unnamed: IC2.7 (QH), U$14.P7 (OUT2)
unnamed: IC4.15 (QA), U$14.P6 (OUT3)
unnamed: IC4.1 (QB), U$14.P5 (OUT4)
unnamed: IC4.2 (QC), R7.1
unnamed: IC4.3 (QD), U$15.P8 (OUT1)
unnamed: IC4.4 (QE), U$15.P7 (OUT2)
unnamed: IC4.5 (QF), U$15.P6 (OUT3)
unnamed: IC4.6 (QG), U$15.P5 (OUT4)
unnamed: IC4.7 (QH), R8.1
unnamed: IC5.1 (QB), U$18.P5 (OUT4)
unnamed: IC5.2 (QC), R11.1
unnamed: IC5.3 (QD), U$19.P8 (OUT1)
unnamed: IC5.4 (QE), U$19.P7 (OUT2)
unnamed: Q20.1 (B), U$10.P1 (IN1)
unnamed: IC5.5 (QF), U$19.P6 (OUT3)
unnamed: IC5.6 (QG), U$19.P5 (OUT4)
unnamed: IC5.7 (QH), R12.1
unnamed: J4.1, Q45.3 (C)
unnamed: J3.1, Q46.3 (C)
unnamed: J3.2, Q47.3 (C)
unnamed: J7.1, J7.2
unnamed: Q11.1 (B), R4.2
unnamed: J12.3, Q28.3 (C)
unnamed: J12.4, Q29.3 (C)
unnamed: Q12.1 (B), U$11.P4 (IN4)
unnamed: J12.5, Q30.3 (C)
unnamed: Q13.1 (B), U$11.P3 (IN3)
unnamed: Q14.1 (B), U$11.P2 (IN2)
unnamed: Q15.1 (B), U$11.P1 (IN1)
unnamed: Q16.1 (B), R3.2
unnamed: Q19.1 (B), U$10.P2 (IN2)
unnamed: Q18.1 (B), U$10.P3 (IN3)
unnamed: Q17.1 (B), U$10.P4 (IN4)
unnamed: Q10.1 (B), U$1.P1 (IN1)
unnamed: Q9.1 (B), U$1.P2 (IN2)
unnamed: Q8.1 (B), U$1.P3 (IN3)
unnamed: J15.1, Q31.3 (C)
unnamed: J15.2, Q32.3 (C)
unnamed: J15.3, Q33.3 (C)
unnamed: J15.4, Q34.3 (C)
unnamed: J15.5, Q35.3 (C)
unnamed: J14.1, Q36.3 (C)
unnamed: J14.2, Q37.3 (C)
unnamed: J14.3, Q38.3 (C)
unnamed: J14.4, Q39.3 (C)
unnamed: J14.5, Q40.3 (C)
unnamed: Q30.1 (B), U$12.P1 (IN1)
unnamed: Q29.1 (B), U$12.P2 (IN2)
unnamed: Q28.1 (B), U$12.P3 (IN3)
unnamed: Q27.1 (B), U$12.P4 (IN4)
unnamed: Q26.1 (B), R5.2
unnamed: Q25.1 (B), R6.2
unnamed: IC2.14 (SER), IC3.9 (QH*)
unnamed: J2.3, Q8.3 (C)
unnamed: J2.4, Q9.3 (C)
unnamed: J2.5, Q10.3 (C)
unnamed: Q40.1 (B), U$14.P1 (IN1)
unnamed: Q39.1 (B), U$14.P2 (IN2)
unnamed: Q38.1 (B), U$14.P3 (IN3)
unnamed: Q37.1 (B), U$14.P4 (IN4)
unnamed: Q36.1 (B), R7.2
unnamed: Q35.1 (B), U$15.P1 (IN1)
unnamed: Q34.1 (B), U$15.P2 (IN2)
unnamed: Q33.1 (B), U$15.P3 (IN3)
unnamed: Q32.1 (B), U$15.P4 (IN4)
unnamed: Q31.1 (B), R8.2
unnamed: Q50.1 (B), U$16.P1 (IN1)
unnamed: Q49.1 (B), U$16.P2 (IN2)
unnamed: Q48.1 (B), U$16.P3 (IN3)
unnamed: Q47.1 (B), U$16.P4 (IN4)
unnamed: Q46.1 (B), R9.2
unnamed: Q45.1 (B), R10.2
unnamed: Q60.1 (B), U$18.P1 (IN1)
unnamed: Q59.1 (B), U$18.P2 (IN2)
unnamed: Q58.1 (B), U$18.P3 (IN3)
unnamed: Q57.1 (B), U$18.P4 (IN4)
unnamed: Q56.1 (B), R11.2
unnamed: Q55.1 (B), U$19.P1 (IN1)
unnamed: Q54.1 (B), U$19.P2 (IN2)
unnamed: Q53.1 (B), U$19.P3 (IN3)
unnamed: Q52.1 (B), U$19.P4 (IN4)
unnamed: Q51.1 (B), R12.2
unnamed: IC1.14 (SER), J1.4
unnamed: J3.3, Q48.3 (C)
unnamed: J3.4, Q49.3 (C)
unnamed: J3.5, Q50.3 (C)
unnamed: J6.1, Q51.3 (C)
unnamed: J6.2, Q52.3 (C)
unnamed: J6.3, Q53.3 (C)
unnamed: J6.4, Q54.3 (C)
unnamed: J6.5, Q55.3 (C)
unnamed: J5.1, Q56.3 (C)
unnamed: J5.2, Q57.3 (C)
unnamed: J5.3, Q58.3 (C)
unnamed: J5.4, Q59.3 (C)
unnamed: J5.5, Q60.3 (C)
RCK: IC1.12 (RCK), IC2.12 (RCK), IC3.12 (RCK), IC4.12 (RCK), IC5.12 (RCK), IC9.12 (RCK), J1.1
SCK: IC1.11 (SCK), IC2.11 (SCK), IC3.11 (SCK), IC4.11 (SCK), IC5.11 (SCK), IC9.11 (SCK), J1.3
SCL: IC1.10 (SCL), IC2.10 (SCL), IC3.10 (SCL), IC4.10 (SCL), IC5.10 (SCL), IC9.10 (SCL), J1.2

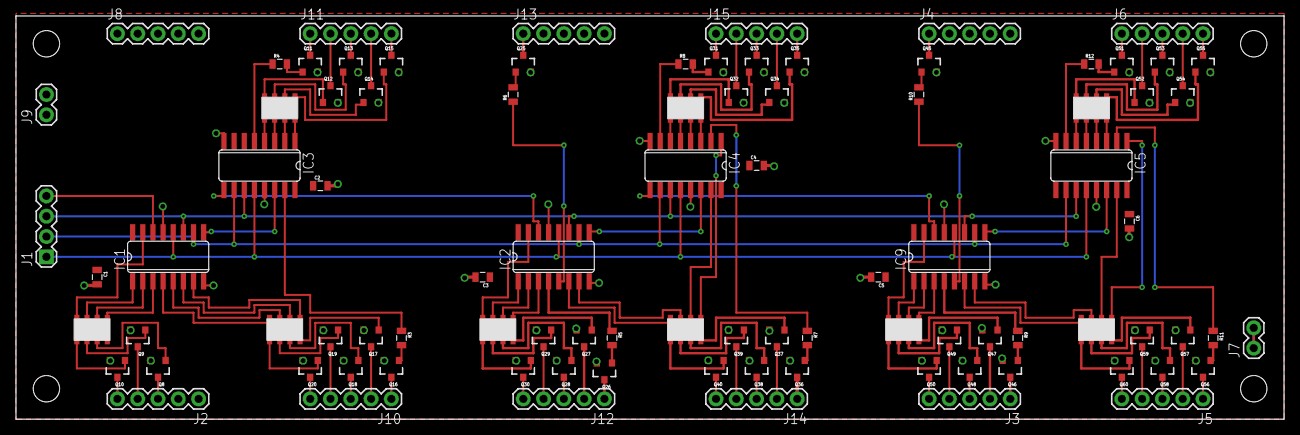
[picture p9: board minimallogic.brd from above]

Board: 2 copper layers, 158.7 x 50.5 mm, 95 parts (0 on the bottom side), 148 nets.

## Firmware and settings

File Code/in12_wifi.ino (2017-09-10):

#include <SPI.h>
#include <WiFi101.h>
#include <WiFiUdp.h>
#include <Time.h>
#include <Timezone.h>

#define DEBUG 1

#if DEBUG
  #define LOG(X) Serial.print(X);
  #define LOGLN(X) Serial.println(X);
#else
  #define LOG(X)
  #define LOGLN(X)
#endif

// High voltage system enable
#define HV_EN 6

// Wifi control
#define WIFI_SS 9
#define WIFI_IRQ 16
#define WIFI_RESET 15
#define WIFI_EN 14

// Shift register control
#define N_SER 19
#define N_SCK 2
#define N_RCK 4
#define N_SCL 3

// How long between NTP re-sync's (millis)
#define NTP_SYNC_INTERVAL 600000
// How long between NTP retrys (millis)
#define NTP_RESEND_INTERVAL 2000

// How long to wait for wifi to connect
#define WIFI_RECONNECT_INTERVAL 10000

// How long between display updates (millis)
#define DISPLAY_UPDATE_INTERVAL 100

#define TIME_SERVER "time.nist.gov"
#define NTP_PORT 123
#define LOCAL_PORT 2390

// Wifi details
#define MAX_SSID_LEN 64
boolean ssidLoaded = false;
uint8_t EEMEM_SSID_LEN EEMEM = 0;
uint8_t EEMEM_PASS_LEN EEMEM = 0;
char EEMEM_SSID[MAX_SSID_LEN] EEMEM = "your_ssid_here";
char EEMEM_PASS[MAX_SSID_LEN] EEMEM = "your_password_here";
char ssid[MAX_SSID_LEN] = {0};
char pass[MAX_SSID_LEN] = {0};

// WIFI101 internals
WiFiUDP Udp;
int wifiStatus = WL_IDLE_STATUS;
unsigned long lastWifiBeginTime = WIFI_RECONNECT_INTERVAL;
const int NTP_PACKET_SIZE = 48;
byte packetBuffer[NTP_PACKET_SIZE];

// Timezone rules
TimeChangeRule usEDT = {"EDT", Second, Sun, Mar, 2, -240};  //UTC - 4 hours
TimeChangeRule usEST = {"EST", First, Sun, Nov, 2, -300};   //UTC - 5 hours
Timezone usEastern(usEDT, usEST);

// State
unsigned long millis_offset = 0;
unsigned long lastNtpPacketSent = NTP_RESEND_INTERVAL;
unsigned long lastNtpSyncSuccess = NTP_SYNC_INTERVAL;
unsigned long lastDisplayUpdate = 0;

/**
 * Set pinmodes, initialize WiFi chipset, enable the high voltage system
 */
void setup() {
    // Initialize serial
    Serial.begin(9600);

    //// Set up pins
    // High voltage shutdown
    pinMode(HV_EN, OUTPUT);

    // Wifi
    pinMode(WIFI_SS, OUTPUT);
    pinMode(WIFI_IRQ, OUTPUT);
    pinMode(WIFI_RESET, OUTPUT);
    pinMode(WIFI_EN, OUTPUT);

    // Shift register
    pinMode(N_SER, OUTPUT);
    pinMode(N_SCK, OUTPUT);
    pinMode(N_RCK, OUTPUT);
    pinMode(N_SCL, OUTPUT);
    digitalWrite(N_SCL, HIGH);

    //// Start wifi
    digitalWrite(WIFI_EN, HIGH);
    delay(250);
    WiFi.setPins(WIFI_SS, WIFI_IRQ, WIFI_RESET, -1);

    // Turn on display
    write595Time(0, 0, 0);
    digitalWrite(HV_EN, HIGH);
}

/**
 * On each loop, there are three things we want to check:
 * - Whether we need to re-sync with the NTP server
 * - Whether there is a pending UDB datagram to handle
 * - Whether it's time to update the display
 */
void loop() {
    // Ensure that the wifi remains connected
    ensureWifi();

    // If it's been more than NTP_SYNC_INTERVAL since we last updated our time
    // offset, then issue a new NTP sync request.
    if (WiFi.status() == WL_CONNECTED
     && millis() - lastNtpSyncSuccess > NTP_SYNC_INTERVAL
     && millis() - lastNtpPacketSent > NTP_RESEND_INTERVAL) {
        LOGLN("Sending new NTP packet");
        sendNTPpacket();
        lastNtpPacketSent = millis();
    }

    // If we have a pending NTP response datagram, handle it
    if (Udp.parsePacket()) {
        LOGLN("Got NTP response");
        parseNtpResponse();
    }

    // If it's been too long since our last refresh of the display, trigger one
    if (millis() - lastDisplayUpdate > DISPLAY_UPDATE_INTERVAL) {
        lastDisplayUpdate = millis();
        updateDisplay();
    }

    while (Serial.available()) {
        handleSerial();
    }
}

#define READY 1
#define READ_SSID 2
#define READ_PASS 3

uint8_t serialState = READY;

char serialBuffer[96];
uint8_t cmdBufferIndex = 0;

void handleSerial() {
    // Read the next character
    int c = Serial.read();

    // If we read a -1, there's no data available
    if (c < 0) {
      return;
    }

    Serial.print(((char)c));

    // Handle the byte depending on our current state
    switch(serialState) {
        case READY:
            // Add the char to the command buffer
            serialBuffer[cmdBufferIndex++] = c;

            // If the buffer has 4 characters, check if it's a valid command
            if (cmdBufferIndex == 5) {
                if (!strncmp("ssid ", serialBuffer, 5)) {
                  serialState = READ_SSID;
                } else if (!strncmp("pass ", serialBuffer, 5)) {
                  serialState = READ_PASS;
                } else {
                  serialState = READY;
                  Serial.println("Invalid cmd");
                }
                cmdBufferIndex = 0;
            }
            break;
        case READ_PASS:
            if (c == '\n' || c == '\r') {
                serialBuffer[cmdBufferIndex++] = 0;
                setWifiPass(serialBuffer, cmdBufferIndex);
                Serial.print("Set Wifi pass to ");
                Serial.println(serialBuffer);
                cmdBufferIndex = 0;
                serialState = READY;
            }
            serialBuffer[cmdBufferIndex++] = c;
            break;
        case READ_SSID:
            if (c == '\n' || c == '\r') {
                serialBuffer[cmdBufferIndex++] = 0;
                setWifiSsid(serialBuffer, cmdBufferIndex);
                Serial.print("Set Wifi ssid to ");
                Serial.println(serialBuffer);
                cmdBufferIndex = 0;
                serialState = READY;
            }
            serialBuffer[cmdBufferIndex++] = c;
            break;
    }
}

void setWifiSsid(char *newSSID, uint8_t len) {
    eeprom_write_block(newSSID, EEMEM_SSID, len);
    eeprom_write_byte(&EEMEM_SSID_LEN, len);
}

void setWifiPass(char *newPass, uint8_t len) {
    eeprom_write_block(newPass, EEMEM_PASS, len);
    eeprom_write_byte(&EEMEM_PASS_LEN, len);
}

/**
 * Update our stored offset of the timezone-local epoch time against our
 * internal millisecond counter.
 */
void updateOffset(unsigned long localTime) {
    millis_offset = (localTime - (millis() / 1000));
}

/**
 * Initialize the WiFi chipset,
 * internal millisecond counter.
 */
void ensureWifi() {
    // If the wifi is connected, and we thought it was connected, do nothing
    if (WiFi.status() == WL_CONNECTED && wifiStatus == WL_CONNECTED) {
        return;
    }

    // Check if we have loaded the SSID details from EEPROM
    if (!ssidLoaded) {
        uint8_t ssidLen = eeprom_read_byte(&EEMEM_SSID_LEN);
        LOG("SSid length: ");
        LOGLN(ssidLen);
        uint8_t passLen = eeprom_read_byte(&EEMEM_PASS_LEN);
        LOG("Pass length: ");
        LOGLN(passLen);
        eeprom_read_block(ssid, EEMEM_SSID, ssidLen);
        eeprom_read_block(pass, EEMEM_PASS, passLen);
        LOG("Loaded wifi details ");
        LOG(ssid);
        LOG(" / ");
        LOGLN(pass);
        ssidLoaded = true;
    }

    // If we're not connected, and it's been long enough since the last attempt,
    // re-begin the wifi connection.
    if (millis() - lastWifiBeginTime > WIFI_RECONNECT_INTERVAL) {
        lastWifiBeginTime = millis();
        LOG("(Re)Connecting to WiFi");
        wifiStatus = WiFi.begin(ssid, pass);
    }

    // If the wifi is connected but we didn't think it was, then we must just have
    // connected, so start a UDP socket up.
    if (wifiStatus == WL_CONNECTED || WiFi.status() == WL_CONNECTED) {
        LOG("Wifi connected");
        wifiStatus = WL_CONNECTED;
        Udp.begin(LOCAL_PORT);
        return;
    }
}

/**
 * Parse the response datagram from the NTP timeserver
 */
void parseNtpResponse() {
    // Read the response packet into the buffer
    Udp.read(packetBuffer, NTP_PACKET_SIZE);

    // The info we care about, the NTP timestamp, begins at byte 40 in the
    // packet and is 4 bytes long. Grab those bytes and convert them to an
    // unsigned long.
    unsigned long highWord = word(packetBuffer[40], packetBuffer[41]);
    unsigned long lowWord = word(packetBuffer[42], packetBuffer[43]);

    // NTP counts seconds since 1900, not seconds since 1970.
    unsigned long secsSince1900 = highWord << 16 | lowWord;

    // So to convert to UNIX epoch, just need to subtract 70 years in seconds
    const unsigned long seventyYears = 2208988800UL;
    unsigned long epoch = secsSince1900 - seventyYears;

    // Now, convert that epoch to our local timezone
    unsigned long localTime =  usEastern.toLocal(epoch);
    LOG("Updated time offset: ");
    LOGLN(localTime);

    // And update our millisecond offset
    updateOffset(localTime);

    lastNtpSyncSuccess = millis();
}


/**
 * Issue an NTP sync request to our timeserver.
 * This involves building up a packet by hand - reference to RFC5905 is key
 * https://tools.ietf.org/html/rfc5905#section-7.3
 */
unsigned long sendNTPpacket() {
    // Zero out our packet buffer
    memset(packetBuffer, 0, NTP_PACKET_SIZE);

    // Our first byte contains the Leap Indicator, Version Number and Mode.
    packetBuffer[0] = (
        // Leap indicator is set to 3 (clock not sync'd)
        0x03 << 6 |
        // Version number is 4, the current version of NTP
        0x04 << 3 |
        // Our mode is 3, client
        0x03 << 0
    );

    // Next is stratum, in this case unspecified
    packetBuffer[1] = 0x00;

    // Polling interval - the maximum interbal between successive messages.
    // This is a funky variable; it's in log2 seconds.
    // 6 is the recommended lower bound, so we'll use that
    packetBuffer[2] = 0x06;

    // The precision of our own clock.
    // This is also in log2 seconds (signed). So to specify microseconds, that's
    // 1 / 1,000,000 seconds. log_2(1000000) is 20 (well, 19,9), so for one
    // onemillionth of a second we want -20.
    packetBuffer[3] = 0xEC;

    // 8 bytes intentionally left blank for the root delay and root dispersion.
    // These count time lags for the reference clock, and we don't really care.

    // Next 32 bits are the Reference ID. I can't quite determine what exactly
    // the spec wants here, but 'INIT' is a valid kiss code for not having
    // synchronized yet so we'll go with that
    packetBuffer[12]  = 'I';
    packetBuffer[13]  = 'N';
    packetBuffer[14]  = 'I';
    packetBuffer[15]  = 'T';

    // There are more fields in an NTP packet, but we don't care about them here
    // Now that the packet is all set, we can send it off to the timeserver
    // NTP runs on port 123
    Udp.beginPacket(TIME_SERVER, NTP_PORT);
    Udp.write(packetBuffer, NTP_PACKET_SIZE);
    Udp.endPacket();
}

/**
 * Updates the Nixie display.
 * Calculate the current local time from our sytem time and millisecond offset,
 * then break it up into hours, minutes and seconds and hand it off to the shift
 * register logic
 */
void updateDisplay() {
    // Take the current system time, convert to seconds and add our offset
    unsigned long time = (millis() / 1000) + millis_offset;

    // Now, modulo the time down to just one day
    time = time % (60L * 60L * 24L);

    // Break out each of the hours, minutes and seconds
    uint8_t hours = (time / 60 / 60) % 24;
    uint8_t minutes = (time / 60) % 60;
    uint8_t seconds = time % 60;

    // Hand the values off to the bit fiddling logic
    write595Time(hours, minutes, seconds);
}

/**
 * Takes the hours, minutes and seconds and maps them into bits on the shift
 * registers. Elegant? Perhaps not. Functional? Yes.
 */
void write595Time(uint8_t hours, uint8_t minutes, uint8_t seconds) {

    // Create an output buffer
    uint8_t out[] = { 0, 0, 0, 0, 0, 0 };

    // Low 3 bites on the first shift register control the hours tens
    switch (hours / 10) {
        case 0: out[0] |= (1 << 0); break;
        case 1: out[0] |= (1 << 1); break;
        case 2: out[0] |= (1 << 2); break;
    }

    // The upper bits of the first, and lower of the second, registers control
    // hours ones
    switch (hours % 10) {
        case 0: out[0] |= (1 << 4); break;
        case 1: out[0] |= (1 << 5); break;
        case 2: out[0] |= (1 << 6); break;
        case 3: out[0] |= (1 << 7); break;

        case 4: out[1] |= (1 << 0); break;
        case 9: out[1] |= (1 << 1); break;
        case 8: out[1] |= (1 << 2); break;
        case 7: out[1] |= (1 << 3); break;
        case 6: out[1] |= (1 << 4); break;
        case 5: out[1] |= (1 << 5); break;
    }

    // Tens places on the minutes
    switch (minutes / 10) {
        case 0: out[2] |= (1 << 0); break;
        case 1: out[2] |= (1 << 1); break;
        case 2: out[2] |= (1 << 2); break;
        case 3: out[2] |= (1 << 3); break;
        case 4: out[2] |= (1 << 4); break;
        case 5: out[2] |= (1 << 5); break;
    }

    // Ones places on the minutes
    switch (minutes % 10) {
        case 0: out[2] |= (1 << 6); break;
        case 1: out[2] |= (1 << 7); break;

        case 2: out[3] |= (1 << 0); break;
        case 3: out[3] |= (1 << 1); break;
        case 4: out[3] |= (1 << 2); break;
        case 9: out[3] |= (1 << 3); break;
        case 8: out[3] |= (1 << 4); break;
        case 7: out[3] |= (1 << 5); break;
        case 6: out[3] |= (1 << 6); break;
        case 5: out[3] |= (1 << 7); break;
    }

    // Tens places on the seconds
    switch (seconds / 10) {
        case 0: out[4] |= (1 << 0); break;
        case 1: out[4] |= (1 << 1); break;
        case 2: out[4] |= (1 << 2); break;
        case 3: out[4] |= (1 << 3); break;
        case 4: out[4] |= (1 << 4); break;
        case 5: out[4] |= (1 << 5); break;
    }

    // Ones places on the seconds
    switch (seconds % 10) {
        case 0: out[4] |= (1 << 6); break;
        case 1: out[4] |= (1 << 7); break;

        case 2: out[5] |= (1 << 0); break;
        case 3: out[5] |= (1 << 1); break;
        case 4: out[5] |= (1 << 2); break;
        case 9: out[5] |= (1 << 3); break;
        case 8: out[5] |= (1 << 4); break;
        case 7: out[5] |= (1 << 5); break;
        case 6: out[5] |= (1 << 6); break;
        case 5: out[5] |= (1 << 7); break;
    }

    // Now shift out the data to the registers
    digitalWrite(N_RCK, LOW);
    for (int i = 5; i >= 0; i--) {
        shiftOut(N_SER, N_SCK, MSBFIRST, out[i]);
    }
    digitalWrite(N_RCK, HIGH);
}

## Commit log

2017-06-29 Import arduino sketch
2017-06-29 Add the EAGLE files
    [control.brd, control.sch, display.brd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]

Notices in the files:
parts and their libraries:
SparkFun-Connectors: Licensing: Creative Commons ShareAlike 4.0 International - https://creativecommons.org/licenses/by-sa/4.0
